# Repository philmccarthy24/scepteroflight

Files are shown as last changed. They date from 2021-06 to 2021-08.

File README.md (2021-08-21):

# Scepter of Light
## 3D printable prop

*Phil McCarthy, August 2021*

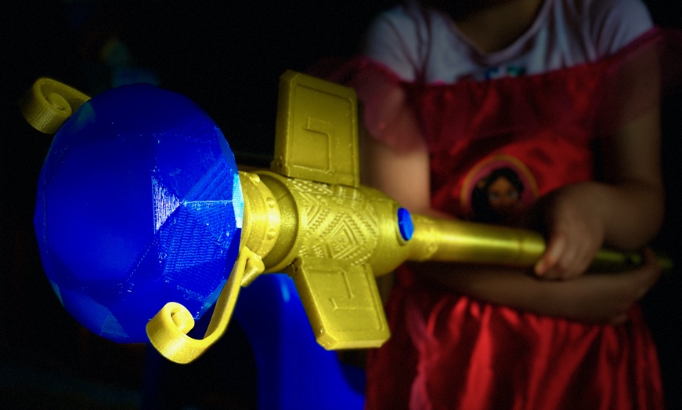
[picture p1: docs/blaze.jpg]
blaze


### What is this?
A 3D printed version of the Scepter of Light from Elena of Avalor, created by Phil McCarthy over summer 2021.

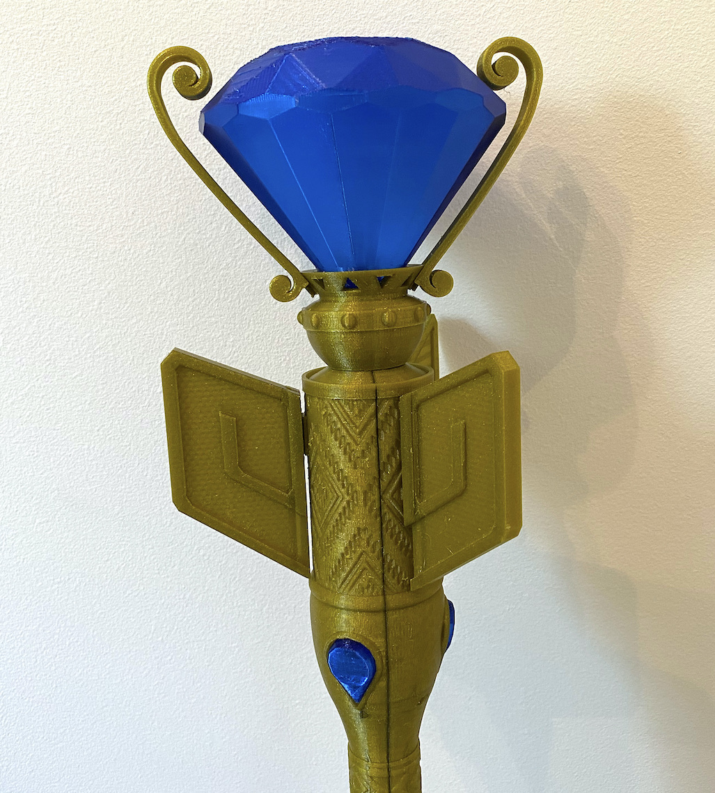
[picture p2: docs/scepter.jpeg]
scepter


### Why?
My daughter loves Elena, and wanted a scepter to go with her costume. I've thought about designing a circuit board and doing some 3D printing for a while - so this was an ideal learning project with the right level of challenge. It took about three months to complete in my spare time.

The scepter lights up and plays music when turned on, and rumbles with "magic" when waved. See a quick [video demo here](https://youtu.be/RlnO9K1_UK8).

I've made [an Instructable](https://www.instructables.com/Scepter-of-Light/) and [a Thing](https://www.thingiverse.com/thing:4937785) to go with this repository, to make it more searchable.

### Features

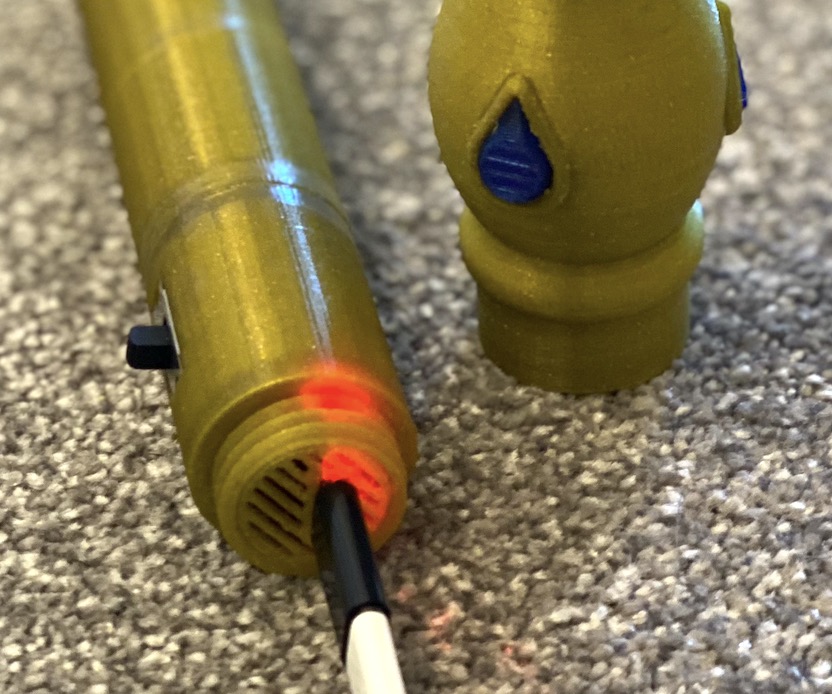
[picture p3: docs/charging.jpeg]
charging
- Easy access charging via MicroUSB port in unscrewable hilt - red light is charging, blue means charged. Grille around port allows heat dissapation during charge. 

- Custom PCB with ULN2003A driver allows independent control of each of the three side ultrabright LEDs, the top ultrabright LED array, and the vibration motor, via the MCU's output pins.

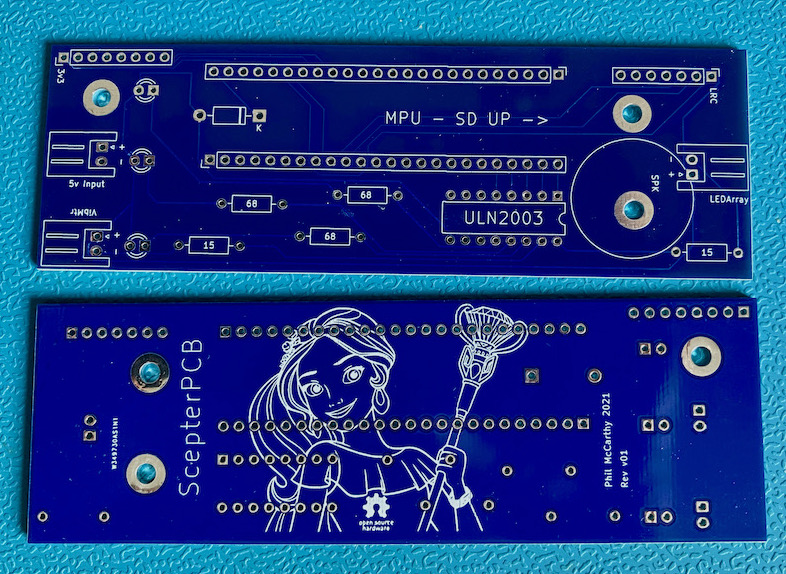
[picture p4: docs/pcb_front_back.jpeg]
pcb
  

- All components on the PCB board are through-hole, allowing easy soldering/assembly, but it's thin enough to fit into the 50mm diameter scepter head.

- High spec Teensy 4.1 MCU with 600 MHz Cortex-M7 processor and 1MB RAM can support gesture recognition via ML (in future).

### What's included in this repository?
Original OpenSCAD designs and related assets for all parts, STL files for unmodified reprints (also Prusa project files which will save you time when slicing if you have a Prusa), KiCAD project files and gerbers for modifying/fabricating the PCB, and documentation.

Included in the documentation is [the full parts list](docs/BOM.md), [assembly instructions](docs/assembly.md), and [the printing settings that worked for me](docs/printing.md) when printing the parts out.

### Any gotchas?

I haven't included wav sound files for potential copyright reasons. You just need to find some appropriate sounds and save them as "theme.wav" and "blaze.wav" on the root of the micro SD card that slots into the microcontroller.

The GY-521 gyro module needs to be mounted onto the PCB upside down, due to a "feature" in the PCB design - this is documented in the assembly instructions.

The sound isn't super-loud. It's acceptably audible, but not room filling. This is because there's little space in the enclosure interior, so I had to opt for a thin 8ohm 0.5W 20mm speaker. As a result the default 9dB gain setting of the MAX98357 distorts the audio through this speaker. I reduced the gain to 6dB by connecting the GAIN pin to Vin, which results in non-distorted (but slightly quieter) audio.

If you have some way of mounting a larger, more powerful speaker (up to 3W), it's possible to get these different gain settings:  

- **15dB** if a 100K resistor is connected between **GAIN** and **GND**
- **12dB** if **GAIN** is connected directly to **GND**
- **9dB** if **GAIN** is not connected to anything
- **6dB** if **GAIN** is connected directly to **Vin** (default PCB wiring)
- **3dB** if a 100K resistor is connected between **GAIN** and **Vin**

You will need to hack the PCB with a craft knife and soldering iron or update the PCB design to achieve these changes.

### What's the future of the project?

I plan to add gesture recognition at some point - the MCU was chosen to be powerful enough to support machine learning and classification of accelerometer data.

I'm not sure when I'm going to get round to coding it in; it might be next year. If you want to implement this yourself, go for it - I'm excited to see what you do!

### Legal stuff
This project is a fan-made artistic prop, not a commercial product, and is free and open source. The PCB design, 3D print designs and MCU firmware are shared under the [GPLv3 license](https://www.gnu.org/licenses/gpl-3.0.en.html).

In particular note the warranty and liability sections - these designs are shared for you to do what you want with them, with the understanding that if they cause harm or damage to you, your property or your loved ones, **you and solely you take full responsibility**.

High capacity Lithium Ion batteries are **dangerous**, should *never* be short circuited, and must be used with care and knowledge. **Please don't assume my circuitry or designs are electrically or mechanically safe.**

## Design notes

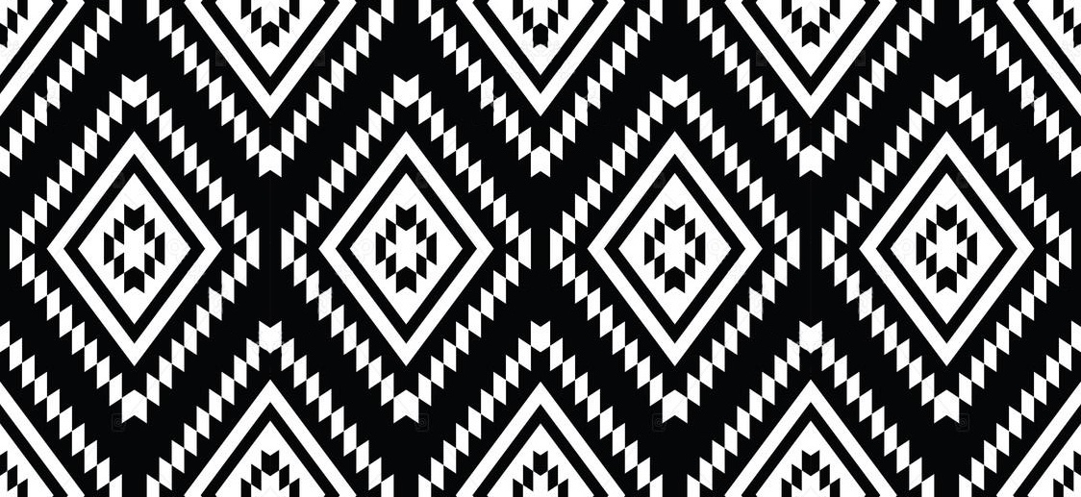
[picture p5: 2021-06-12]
openscad/assets/tiptexture.jpg

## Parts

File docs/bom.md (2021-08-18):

# Scepter of Light
## 3D printable prop

*Phil McCarthy, August 2021*

### BOM / required components list

#### Head assembly

| Item | Quantity | Part Cost (min/bulk) | Line cost | Example link |
|:--|:--|:--|:--|:--|
| M2 3.5x4 brass screw insert | 2 | £11.49 | £0.07 |  [Amazon1](https://www.amazon.co.uk/gp/product/B07QR6GVFJ/ref=ppx_yo_dt_b_asin_title_o03_s00?ie=UTF8&psc=1) |
| M3 5x4 brass screw insert | 3 | As above | £0.07 | As above |
| M2 Stainless Steel pan-head machine screw, 10mm length | 1 |  £8.99 | £0.07 | [Amazon2](https://www.amazon.co.uk/gp/product/B07F152LLX/ref=ppx_yo_dt_b_asin_title_o01_s00?ie=UTF8&psc=1)
| M2 Stainless Steel pan-head machine screw, 12mm length | 1 |  As above | £0.07 | As above |
| M3 nylon PCB screw 4mm length | 3 | £10.76 | £0.11 | [Amazon3](https://www.amazon.co.uk/HALJIA-Circuit-Standoff-Cylinder-Assorted/dp/B06WWBHMQ3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)
| MT3608 voltage regulator | 1 | £6.49 | £1.30 | [Amazon4](https://www.amazon.co.uk/dp/B084V25CCP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)
| Female 2 pin 2.5mm pitch JST SM connector | 1 | £8.59 | £0.02 | [Amazon5](https://www.amazon.co.uk/gp/product/B0716JMHNJ/ref=ppx_yo_dt_b_search_asin_title?ie=UTF8&psc=1) |
| 2 pin JST-XHP plug | 1 | £16.99 | £0.42 | [Amazon6](https://www.amazon.co.uk/gp/product/B07CTH46S7/ref=ppx_yo_dt_b_search_asin_title?ie=UTF8&psc=1) |

#### Components for PCB & LED stalk

| Item | Quantity | Part Cost (min/bulk) | Line cost | Example link |
|:--|:--|:--|:--|:--|
| ULN2003A | 1 | £2.05 | £0.41 | [Rapid1](https://www.rapidonline.com/Catalogue/Search?Query=Uln2003) |
| Teensy 4.1 MCU | 1 | £33.81 | £33.81 | [Amazon7](https://www.amazon.co.uk/Teensy-4-1-Without-Pins/dp/B088D3FWR7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) |
| Micro vibration motor cell 3V 75mA | 1 | £6.49 | £0.81 | [Amazon8](https://www.amazon.co.uk/gp/product/B074M24S21/ref=ppx_yo_dt_b_search_asin_image?ie=UTF8&psc=1) |
| ST 1N5819 Schottky Diode 40V 1A DO41 | 1 | £1.19 | £0.23 | [Rapid2](https://www.rapidonline.com/st-1n5819-schottky-diode-40v-1a-do41-47-2566) |
| Pin headers various | 1 | £5.07 | £5.07 | [Amazon9](https://www.amazon.co.uk/gp/product/B01M69EA9O/ref=ppx_yo_dt_b_asin_title_o09_s00?ie=UTF8&psc=1) |
| 68ohm resistor, through-hole | 3 | £11.99 | £0.03 | [Amazon10](https://www.amazon.co.uk/gp/product/B07P1GWKSJ/ref=ppx_yo_dt_b_asin_title_o09_s00?ie=UTF8&psc=1) |
| 15ohm resistor, through-hole | 2 | As above | £0.02 | As above |
| 5mm ultrabright white LEDs 3V(f) 20mA | 6 | £4.32 | £0.24 | [Amazon11](https://www.amazon.co.uk/gp/product/B01AUI4VQU/ref=ppx_yo_dt_b_asin_title_o03_s00?ie=UTF8&psc=1) |
| JST-XH S2B 2 pin 2.5 pitch header | 2 | £1.66 | £0.16 | [Rapid3](https://www.rapidonline.com/jst-s2b-xh-a-lf-sn-2-pole-side-entry-xh-series-p2-5mm-22-5340) |
| JST-XH B2B 2 pin 2.5 pitch header | 2 | As Amazon6 | £0.84 | As Amazon6 |
| 2 pin JST-XHP plug | 1 | As Amazon6 | £0.42 | As Amazon6 |
| MAX98357A | 1 | £5.92 | £5.92 | [CoolComponents1](https://coolcomponents.co.uk/products/i2s-3w-class-d-amplifier-breakout-max98357a?_pos=2&_sid=e4bcb1d9f&_ss=r) |
| 20mm 0.5W 8ohm flat speaker | 1 | £10.10 | £2.02 | [RS1](https://uk.rs-online.com/web/p/miniature-speakers/1797441)
| GY-521 MPU6050 | 1 | £6.99 | £2.33 | [Amazon12](https://www.amazon.co.uk/gp/product/B07P5YXBXV/ref=ppx_yo_dt_b_search_asin_image?ie=UTF8&psc=1) |
| 16GB micro SD card | 1 | £4.68 | £4.68 | [Amazon15](https://www.amazon.co.uk/gp/product/B073K14CVB/ref=ppx_yo_dt_b_search_asin_image?ie=UTF8&psc=1)

#### Battery module

| Item | Quantity | Part Cost (min/bulk) | Line cost | Example link |
|:--|:--|:--|:--|:--|
| Male 2 pin 2.5mm pitch JST SM connector | 1 | As Amazon5 | £0.02 | As Amazon5 |
| 18650 battery holder (for terminal parts) | 1 | £6.92 | £0.69 | [Amazon13](https://www.amazon.co.uk/gp/product/B075TZF7NN/ref=ppx_yo_dt_b_search_asin_image?ie=UTF8&psc=1) |
| TP4056 charging module | 1 | £2.99 | £0.60 | [Amazon14](https://www.amazon.co.uk/gp/product/B01DRT4PWY/ref=ppx_yo_dt_b_search_asin_title?ie=UTF8&psc=1) |
| Panel mount slide switch | 1 | £3.19 | £3.19 | [RS2](https://uk.rs-online.com/web/p/slide-switches/7347312/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) |
| 18650 2500mAH 3.7v LIon rechargeable battery | 1 | £4.99 | £4.99 | [FogStar1](https://www.fogstar.co.uk/products/samsung-25r-br-2500mah-20a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) |

#### Miscellaneous
22 gauge wires, eg [from here](https://www.amazon.co.uk/gp/product/B00B4ZQ3L0/ref=ppx_yo_dt_b_search_asin_image?ie=UTF8&psc=1).

This comes to £68.61 for all the components required for a single sceptre build, not including minimum quantities required, 3D printing costs or PCB fabrication costs. Worth noting that half the component cost is the (massively overspec'd until machine learning is added) MCU; you will be able to redesign cheaper if you don't need gesture recognition.

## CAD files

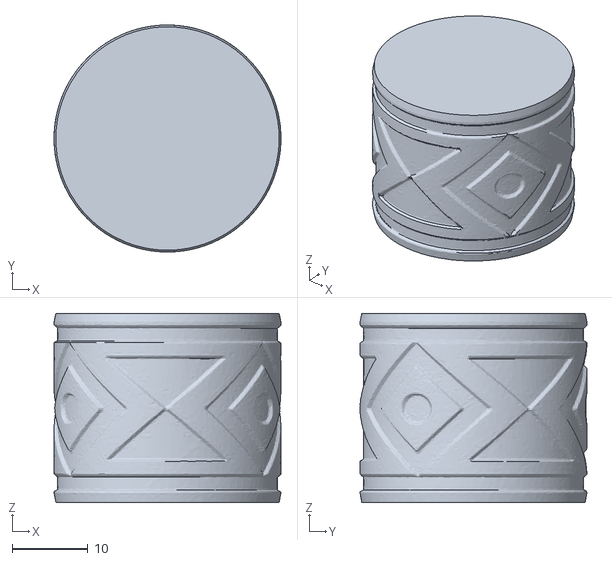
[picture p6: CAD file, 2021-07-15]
openscad/assets/scepterheadjoin.stl
30.0 x 30.0 x 25.0

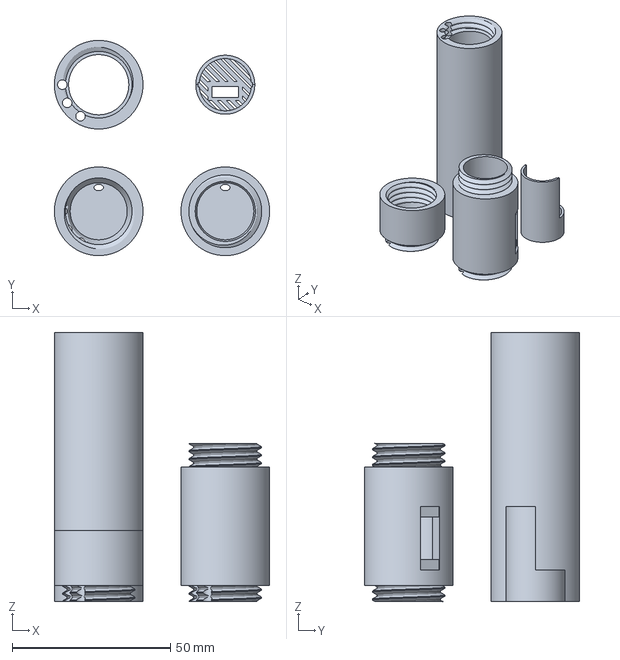
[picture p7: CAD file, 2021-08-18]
stl/batterymodule.3mf
68.0 x 68.0 x 85.0 mm

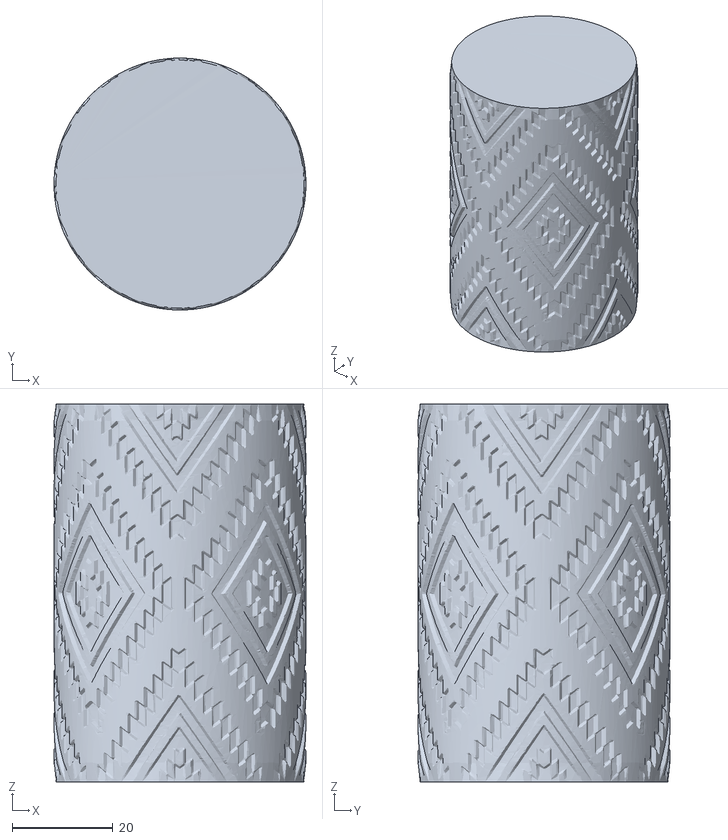
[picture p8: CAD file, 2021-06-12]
openscad/assets/scepterheadwrap.stl
50.0 x 50.0 x 75.0

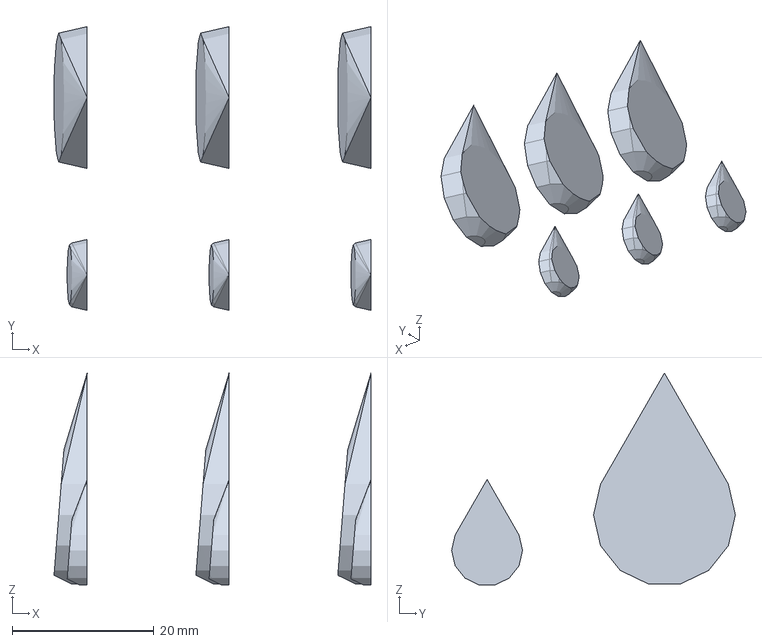
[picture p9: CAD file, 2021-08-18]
stl/teargems.3mf
44.7 x 40.0 x 29.9 mm

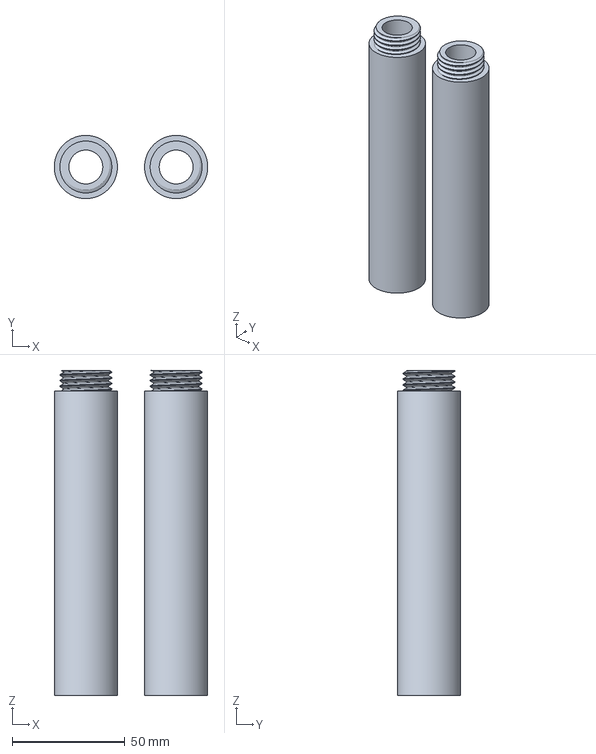
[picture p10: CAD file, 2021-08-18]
stl/shaft.3mf
68.0 x 28.0 x 144.0 mm

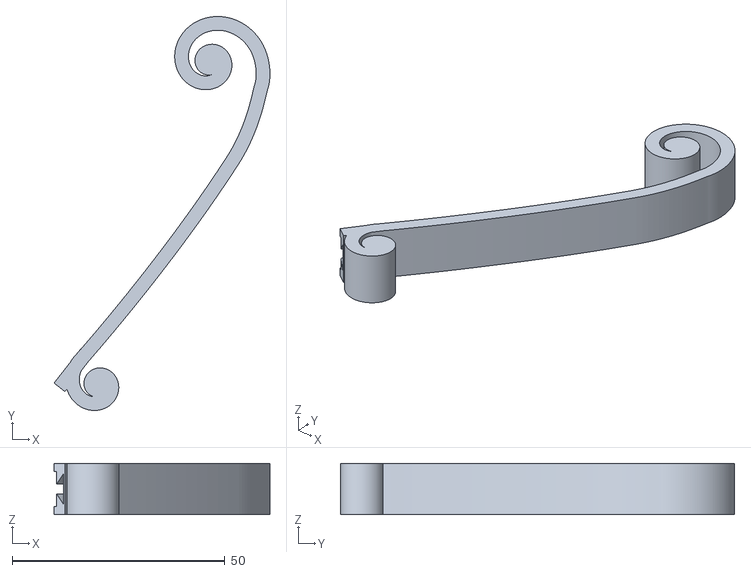
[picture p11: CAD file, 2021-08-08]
stl/gem_curl.stl
50.7 x 92.5 x 12.0

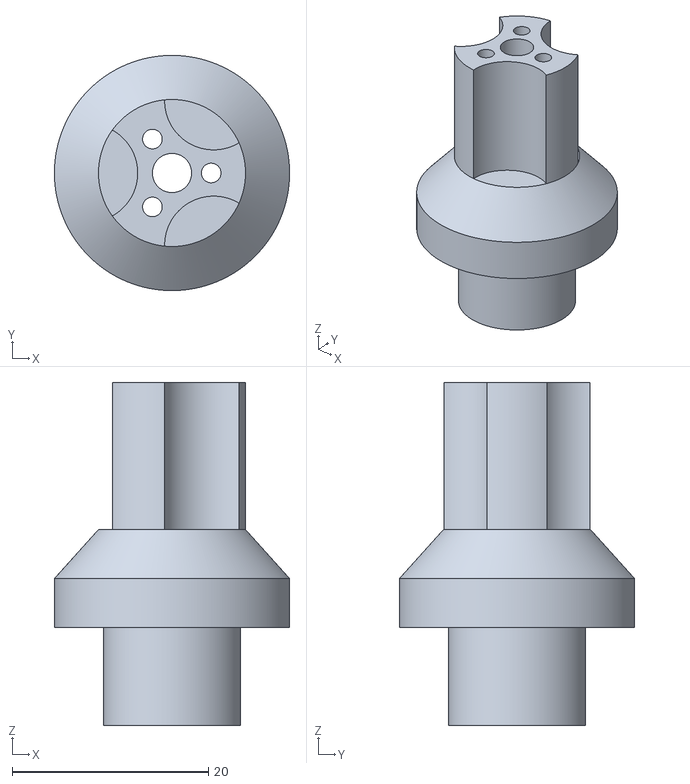
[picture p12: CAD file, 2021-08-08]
stl/stalk.stl
24.0 x 24.0 x 35.0

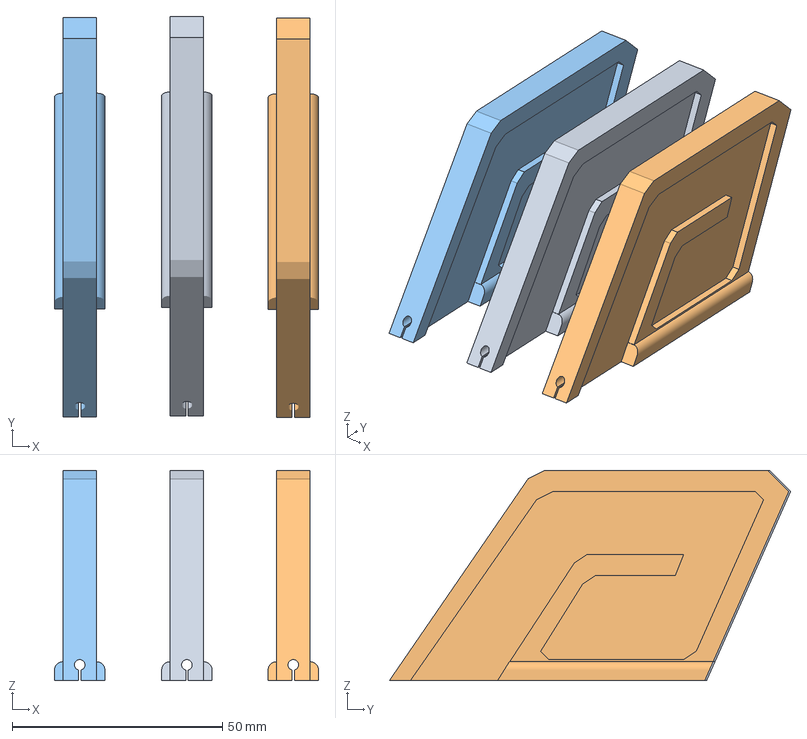
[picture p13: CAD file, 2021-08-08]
stl/headwing.3mf
62.8 x 95.5 x 50.0 mm
headwing.stl x 3

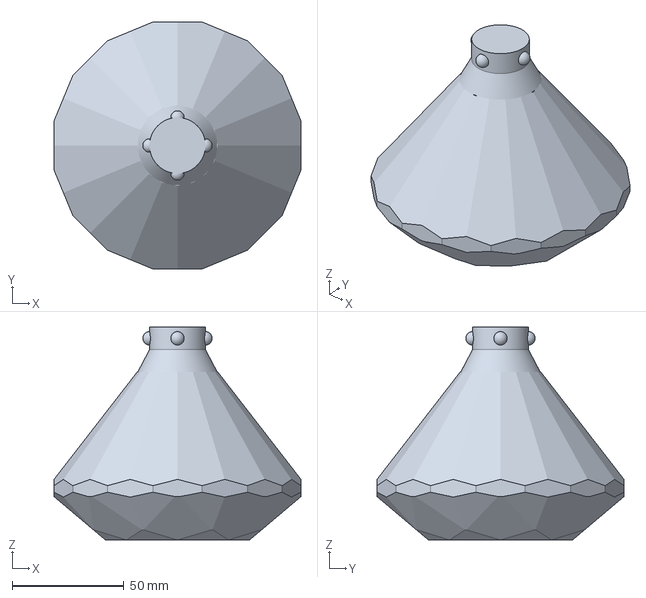
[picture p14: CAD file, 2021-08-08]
stl/gem.3mf
110.5 x 110.5 x 95.2 mm

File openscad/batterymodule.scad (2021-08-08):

use <common.scad>
use <BOSL/constants.scad>
include <BOSL/threading.scad>

$fn = 250;

/****************************************************
* MK4 18650 battery module design
* Phil McCarthy, 2021
* 
* Distributed under the terms of the GPLv3 license:
* https://www.gnu.org/licenses/gpl-3.0.en.html
****************************************************/

shaftDiameter = 28;
batteryDiameter = 19;
batteryLength = 65 - 2; // 1mm less on each side for tension on spring terminals
batteryConnectorSpace = 6;
batteryCompartmentScrewLength = 5;
wireDiameter = 3;
screwThreadPitch = 2.5;


// Main 18650 battery compartment, with 3mm diameter wire runs going down the side
translate([-40,0,0])
batteryCompartment(length=batteryLength + (batteryConnectorSpace * 2) + (batteryCompartmentScrewLength * 2), outerDiameter=shaftDiameter, innerDiameter=batteryDiameter, terminalScrewTapLength=batteryCompartmentScrewLength, terminalScrewTapDiameter=shaftDiameter-5, terminalScrewPitch=screwThreadPitch);

// Positive terminal screw-on adaptor, bolt to bore/tap. This
// has the JST SM connector sticking out, for connection to
// PCB
translate([-40,-40,0])
positiveTerminalAdaptor();

// Negative terminal screw-on adaptor, bolt to bolt with space
// for on/off slide switch and TO4056 support housing.
translate([0,-40,0])
negativeTerminalAdaptor();

// TO4056 support
TP4056holder();


// this is the battery terminal plug, with a shaft screw added to connect
// to upper shaft sections
module positiveTerminalAdaptor() {
    
    difference() {
        union() {
            batteryTerminalPlug(length=12.5, outerDiameter=shaftDiameter, innerDiameter=batteryDiameter, terminalScrewLength=5, terminalScrewDiameter=shaftDiameter-5, terminalScrewPitch=screwThreadPitch, terminalPlateDepth=2);
            translate([0,0,12.5]) cylinder(h=10, d=shaftDiameter);
        }
        // hollow widening to upper shaft screw tap
        translate([0,0,5]) cylinder(h=5+screwThreadPitch, d1=(shaftDiameter-5)-screwThreadPitch*2,d2=shaftDiameter-5);
        // connection screw tap
        translate([0, 0, 12.5]) threaded_rod(d = shaftDiameter - 5, l = 11, pitch = screwThreadPitch, internal = true, slop = 0.25, orient=ORIENT_Z, align=V_UP);
    };
}

// this is the battery terminal plug, with housing inside a plug added for
// on off switch and TP4056 module
module negativeTerminalAdaptor() {
    
    accessPortRadius = ((batteryDiameter + 4) / 2) + 1.5;
    
    difference() {
        union() {
            // plug with terminal glued on outside
            batteryTerminalPlug(length=12.5, outerDiameter=shaftDiameter, innerDiameter=batteryDiameter, terminalScrewLength=5, terminalScrewDiameter=shaftDiameter-5, terminalScrewPitch=screwThreadPitch, terminalPlateDepth=2);
            // body of adaptor
            translate([0,0,12.5]) cylinder(h=30, d=shaftDiameter);
            // hollow plug to connect to hilt, which will contain TO4056 housing
            translate([0, 0, 40]) threaded_rod(d = shaftDiameter - 5, l = 10, pitch = screwThreadPitch, slop=0, orient=ORIENT_Z, align=V_UP);
        }
        // hollow of adaptor
        translate([0,0,5+screwThreadPitch]) cylinder(h=46, d=batteryDiameter);
        
        // hole for on/off switch
        rotate([0,0,120])
        translate([7/2,-shaftDiameter/2,30])
        rotate([90,90,180]) {
            cube([20, 7, 1]);
            translate([(20-13.5)/2, 0,1]) cube([13.5, 7, 6]);
        };
        
        // ramp to facilitate pushing wires through
        translate([0,0,12.5])
        intersection() {
            cylinder(h=10, r1=accessPortRadius, r2=batteryDiameter/2);
            rotate([0,0,170]) pie(angle=80, radius=accessPortRadius, depth=10);
        }
    };
}

module TP4056holder() {
    coverPlateDepth=1;
    to4056Width=16.5;
    holderLength = 30;
    holderDiameter = shaftDiameter - 9.35;
    
    difference() {
        // main volume
        cylinder(h=holderLength, d=holderDiameter);
        // hollow
        translate([0,0,coverPlateDepth]) cylinder(h=holderLength, d=to4056Width);
        // trailing housing
        translate([-holderDiameter/2,0,10]) cube([holderDiameter,holderDiameter/2,holderLength]);
        // grooves for 4056
        translate([-17.3/2, -1.5/2, coverPlateDepth]) cube([17.3, 1.5, holderLength]);
        // microusb opening
        translate([-8.5/2,-4,-1]) cube([8.5,3.5,3]);
        // grille
        intersection() {
            difference() {
                translate([0,0,-1]) cylinder(h=3, d=to4056Width);
                translate([-11/2,-5,-1]) cube([11,6,3]);
            }
            rotate([0,0,45]) {
                for (x = [0:2:holderDiameter]) {
                    translate([x-holderDiameter/2, -holderDiameter/2, -1]) cube([0.75, holderDiameter, 3]);
                }
            }
        }
    }
}

module batteryTerminalPlug(length, outerDiameter, innerDiameter, terminalScrewLength, terminalScrewDiameter, terminalScrewPitch, terminalPlateDepth) {
    difference() {
        union() {
            // screw with terminal seated on outer face.
            threaded_rod(d = terminalScrewDiameter, l = terminalScrewLength, pitch = terminalScrewPitch, slop=0, orient=ORIENT_Z, align=V_UP);
            // body of adaptor
            translate([0,0,terminalScrewLength]) cylinder(h=length-terminalScrewLength, d=outerDiameter);
        }
        // hollow part of screw
        translate([0,0,terminalPlateDepth]) cylinder(h=terminalScrewLength-terminalPlateDepth, d=terminalScrewDiameter-(terminalScrewPitch*2));
        // widening to main hollow area
        translate([0,0,terminalScrewLength]) cylinder(h=terminalScrewPitch, d1=terminalScrewDiameter-(terminalScrewPitch*2), d2=innerDiameter);
        // main hollow area
        translate([0,0,terminalScrewLength+terminalScrewPitch]) cylinder(h=length-(terminalScrewLength+terminalScrewPitch)+1, d=innerDiameter);
        // hole for terminal prong
        translate([0,7.5,-1]) scale([3,2,1]) cylinder(h=4, d=1);
        // wire runs to access port
        wireDiameter=3;
        wireRunRadius=(innerDiameter + wireDiameter + 1) / 2;
        rotate([0,0,180])
        translate([0,0,-1]) wireRuns(numWires=3, wireRunRadius=wireRunRadius, wireDiameter=wireDiameter, runOffsetAngle=30, runLength=terminalScrewLength+5+1);
        // access port
        translate([0,0,terminalScrewLength+terminalScrewPitch]) rotate([0,0,170]) pie(angle=80, radius=wireRunRadius+(wireDiameter/2), depth=length-(terminalScrewLength+terminalScrewPitch));
    };
}

module batteryCompartment(length, outerDiameter, innerDiameter, terminalScrewTapLength, terminalScrewTapDiameter, terminalScrewPitch) {
    difference() {
        // main volume
        cylinder(h=length, d=outerDiameter);
        // hollow interior
        translate([0,0,-1]) cylinder(h=length+2, d=innerDiameter);
        // bottom screw runs up in z counter-clockwise, with part oriented
        // z up.
        // bottom screw tap, with rotation compensation from trial and error
        // rotate([0,0,240]) - old value
        rotate([0,0,150]) translate([0,0,-terminalScrewPitch]) threaded_rod(d=terminalScrewTapDiameter, l = terminalScrewTapLength+terminalScrewPitch, pitch = terminalScrewPitch, internal = true, slop = 0.25, orient=ORIENT_Z, align=V_UP);
        // top screw tap, with rotation compensation from trial and error
        //rotate([0,0,150]) - old value
        rotate([0,0,180]) translate([0,0,length-terminalScrewTapLength]) threaded_rod(d=terminalScrewTapDiameter, l = terminalScrewTapLength+1, pitch = terminalScrewPitch, internal = true, slop = 0.25, orient=ORIENT_Z, align=V_UP);
        // runs
        wireDiameter=3;
        rotate([0,0,180]) translate([0,0,-1]) wireRuns(numWires=3, wireRunRadius=(innerDiameter + wireDiameter + 1) / 2, wireDiameter=wireDiameter, runOffsetAngle=30, runLength=length+2); 
    }
}

// creates geometry for differencing
module wireRuns(numWires, wireRunRadius, wireDiameter, runOffsetAngle, runLength) {
    for (wireNum = [0:numWires-1]) {
        wireRunAngle = wireNum*runOffsetAngle;
        translate([wireRunRadius * cos(wireRunAngle), wireRunRadius * sin(wireRunAngle),0]) cylinder(h = runLength, d = wireDiameter);
    }
}

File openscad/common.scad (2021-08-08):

/*********************************************
* Common modules for Scepter of Light
* Phil McCarthy, 2021
* 
* Distributed under the terms of the GPLv3 license:
* https://www.gnu.org/licenses/gpl-3.0.en.html
****************************************************/

// render a tear shaped gem
module tear_gem(radius, tip_offset, height) {
    hull($fn=14) {
        difference() {
            union() {
                sphere(r=radius);
                cylinder(h=tip_offset, r1=radius/2, r2=0);
            }
            translate([-radius,-radius,-radius]) cube([radius*2, radius, radius+tip_offset]);
            rotate([4.5,0,0]) translate([-radius,height,-radius]) cube([radius*2, radius-height, radius+tip_offset]);
        };
    };
}

// render a seat for a tear gem
module tear_gem_seat(radius, tip_offset, height) {
    render() {
        difference() {
            tear_gem_seat_outline(radius, tip_offset, height);
            translate([0,0,1]) linear_extrude(height) {
                gem_2d(radius+0.25, tip_offset+0.25);
            };
        }
    }
}

module tear_gem_seat_outline(radius, tip_offset, height) {
    render() {
        difference() {
            minkowski(convexity=3) {
                sphere(r=height/2);
                linear_extrude(1) {
                    gem_2d(radius, tip_offset, 50);
                }
            };
            translate([-radius*2, -radius*2, -height]) cube([(radius+tip_offset)*2, radius*4, height]);
        }
    }
}

module gem_2d(radius, tip_offset, numsides=14) {
    hull($fn=numsides) {
        circle(r=radius);
        translate([tip_offset-((radius/10)/2), 0, 0]) circle(r=radius/10, $fn=3);
    }
}

// center a cube in the xy plane
module centred_xy_cube(dims) {
    translate([-(dims.x/2), -(dims.y/2), 0]) cube(dims);
}

// put child objects in a ring - quite proud of this one :)
module make_ring(ringradius, count) {
    drawangle = 360/count;
    for(item = [0 : count]) {
        a = drawangle * item;
        translate([ringradius * cos(a), ringradius * sin(a)]) rotate([0,0,270+a]) children();
    }
}

// yum
module pie(angle, radius, depth) {
    rotate_extrude(angle = angle, convexity = 10) square([radius,depth]);
}

module pill(xlen, ylen, depth) {
    translate([(ylen/2)-(xlen/2),0,0])
    linear_extrude(depth, true)
    hull() {
        circle(d=ylen);
        translate([xlen-ylen,0,0]) circle(d=ylen);
    }
}

module curve_fastener() {
    scale([1,2,1]){
        translate([0,-2,0]) cube([1,4,10]);
        translate([2,0,0]) rotate([0,0,60]) cylinder(h=10,d=4, $fn=3);
    }
}

module wing_fastener() {
    rotate([0,0,90])
    scale([1,2,1]){
        translate([0,-2,0]) cube([3,4,15]);
        translate([4,0,0]) rotate([0,0,60]) cylinder(h=15,d=4, $fn=3);
    }
}

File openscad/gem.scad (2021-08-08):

/****************************************************
* Scepter of Light Top Gem design
*
* Adapted from a design by Kit Wallace, original at:
* https://github.com/KitWallace/openscad/blob/master/gem.scad
*
* Phil McCarthy, 2021
* 
* Distributed under the terms of the GPLv3 license:
* https://www.gnu.org/licenses/gpl-3.0.en.html
****************************************************/

use <common.scad>

function make_facets(start,increment,limit,axial_angle,height) =
    start <= limit
      ? concat([[start/limit*360, axial_angle, height]] ,
               make_facets(start+increment,increment,limit,axial_angle,height))
      : [] ;

module body(Size=100) {
    cube(Size,center=true);
}

module cut_facet_data(index_angle,axial_angle,height,Width=200,Depth=50) {
     rotate([0,0,index_angle])
        rotate([0,axial_angle,0])
           translate([0,0,Depth/2 + height])
              cube([Width,Width,Depth],center=true);
}

module cut_facets(facets, n) {
   for (i =[0:n-1]) 
       cut_facet(facets[i]);
}

module cut_facet(facet) {
   cut_facet_data(facet[0],facet[1],facet[2]);
}

module gem(facets,n) {
   difference() {
      if (n==1) body(); else gem(facets,n-1);
      cut_facet(facets[n-1]);
   }
}

function brilliant_facets() =
 concat( 
   make_facets(1,1,1,0,2.28),      // table
   make_facets(1,1,1,180,7.8),     // culet
   make_facets(1,2,32,35,5),       // B
   make_facets(4,4,32,30,4.46),    // M
   make_facets(2,4,32,16,3.46),    // S
   make_facets(2,2,32,90,8.5),     // girdle
   make_facets(1,2,32,42+180,6)    // C
 ); 

facets = brilliant_facets();
// echo (len(facets), facets);

difference() {
    translate([0,0,21.5]) rotate([180,0,0]) scale([6.5,6.5,9.5]) gem(facets,len(facets));
    translate([0,0,75]) cylinder(h=25,d=100);
    //translate([0,0,-1]) cylinder(h=74, d=160); // debug
}

// 45 degree cone around bayonet
translate([0,0,75]) cylinder(h=10, d1=35.5,d2=25, $fn=250);
translate([0,0,85]) cylinder(h=10, d=25, $fn=250);
translate([0,0,90]) make_ring(25/2, 4) sphere(d=6, $fn=100); 

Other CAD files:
openscad/gem_curl.scad
openscad/assets/scepterheadjoin.blend
openscad/assets/scepterheadwrap.blend
openscad/head.scad
openscad/headwing.scad
openscad/hilt.scad
openscad/shaft.scad
openscad/stalk.scad
openscad/teargems.scad
openscad/thistle.scad
stl/batterymodule.stl
stl/gem.stl
stl/headwing.stl
stl/shaft.stl
stl/teargems.stl

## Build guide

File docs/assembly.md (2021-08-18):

# Scepter of Light
## 3D printable prop

*Phil McCarthy, August 2021*

### Assembly instructions

See [the BOM](../docs/bom.md) for the list of components required to complete this build. You will also need:

- A soldering iron
- Wire cutters
- Pliers
- A drill
- A multimeter
- Superglue (I used Araldite)
- Gluegun

#### 1. Fabricate PCB

Get the PCB fabricated from a board house using the [gerber files](../pcb/sofpcb_rev01_gerber.zip) (I used [PCBWay](https://www.pcbway.com), they were fairly priced and efficient), and wait two weeks for them to arrive. There's typically a 5 board minimum order.

#### 2. Print parts

Print the STL files. [These are the settings](../docs/printing.md) I found worked for me. Use different settings if they work better for you or your printer. I used [gold filament](https://shop.prusa3d.com/en/prusament/958-prusament-petg-yellow-gold-transparent-1kg.html) for the scepter body parts, and [transparent blue](https://www.amazon.co.uk/gp/product/B07T7MBGVL/ref=ppx_yo_dt_b_search_asin_title?ie=UTF8&psc=1) for the gems. In about a week you should have the following printed parts (red shown instead of blue in photo):

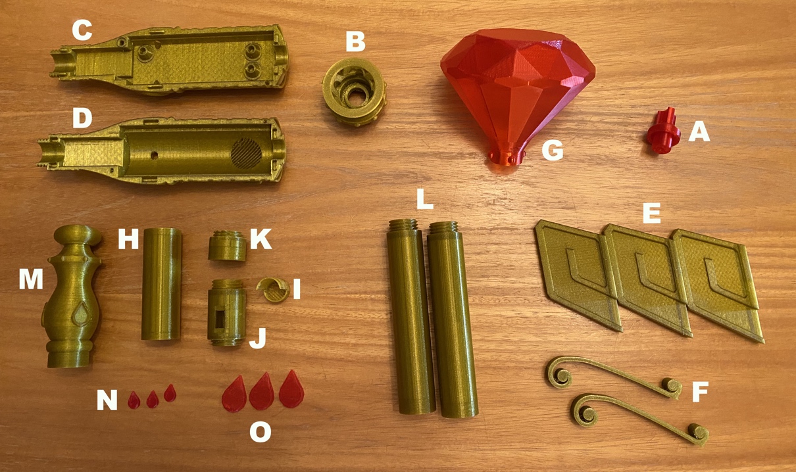
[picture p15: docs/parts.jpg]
parts


- A: LED stalk (blue)
- B: Thistle
- C: Left head
- D: Right head
- E: 3 wings
- F: Top gem curls (gold)
- G: Top gem
- H: 18650 battery case
- I: TP4056 sleeve
- J: Neg terminal screw with switch mount
- K: Pos terminal screw
- L: 2 shaft sections
- M: Hilt
- N: 3 hilt gems
- O: 3 head gems

#### 3. Assemble LED stalk

Take the LED stalk (A), and 3 of the LEDs. Twist the short leads (cathodes) together, and solder on a black wire (long enough to reach the PCB bay below). Solder 3 wires to each of the anodes. 

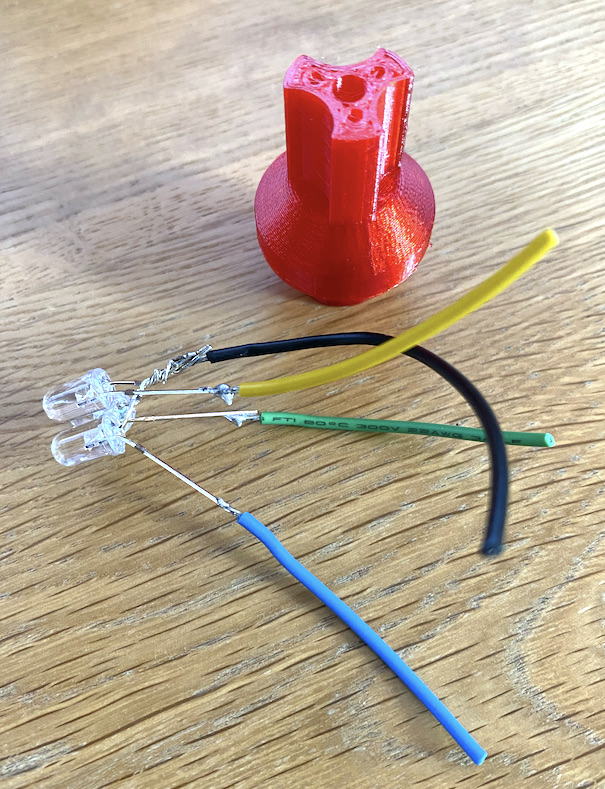
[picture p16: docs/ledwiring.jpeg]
ledwiring


Thread the LED wires through the holes at the top of the LED stalk, black wire in the center, until the LEDs sit flush with the top. Take care that none of the anode leads are left touching the joined cathode lead.

At the base of the stalk, cut, bare and twist the three anode wires together, and solder to them a single positive wire. Put a JST-XH plug on the end of the two stalk wires (note polarity of pcb header).

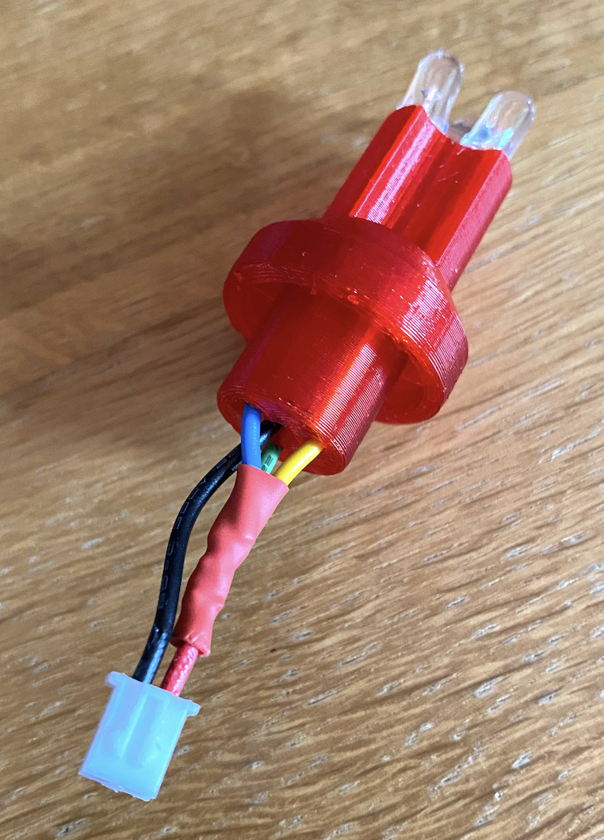
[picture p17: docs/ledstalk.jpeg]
ledstalk


Screw the stalk into the interior of the Thistle (B). 

#### 4. Prepare scepter head

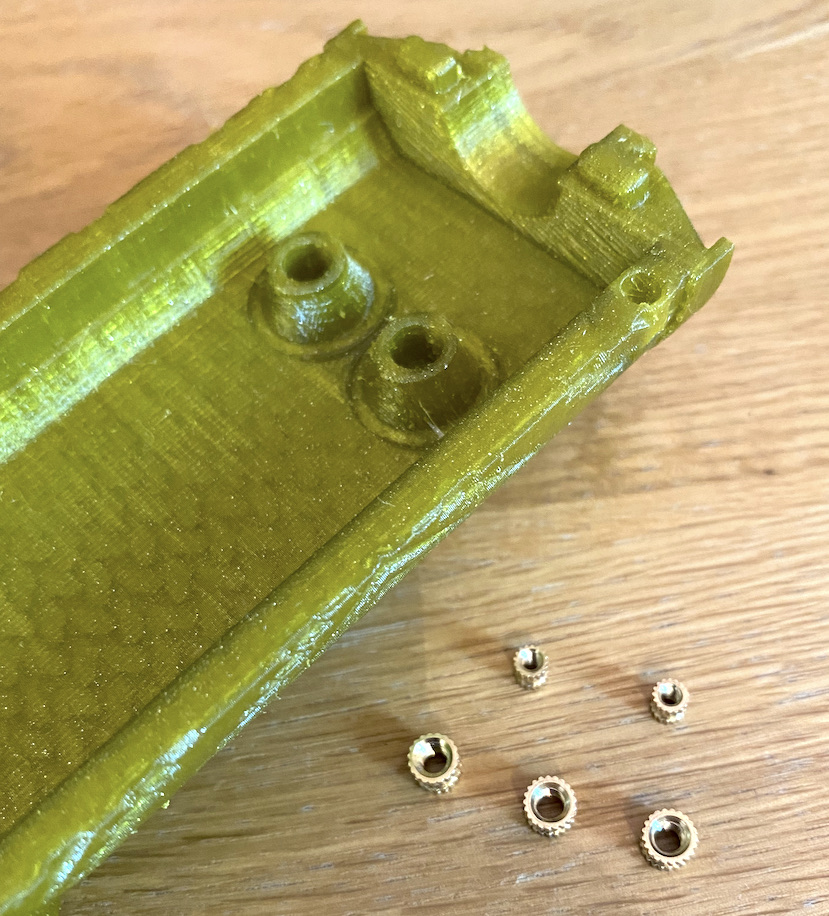
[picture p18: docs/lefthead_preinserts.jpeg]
preinserts


Set your soldering iron to 300 degrees Celcius. Take the M2 and M3 brass inserts and seat them into the corresponding holes in the left head part (C); M2 inserts in top right and bottom left holes, M3 inserts in each PCB standoff hole. Touch the soldering iron tip to each brass insert in turn, pushing it down into the melting plastic. Stop at the last mm, then quickly use a small piece of flat metal to push the inserts fully in, so they sit flush.

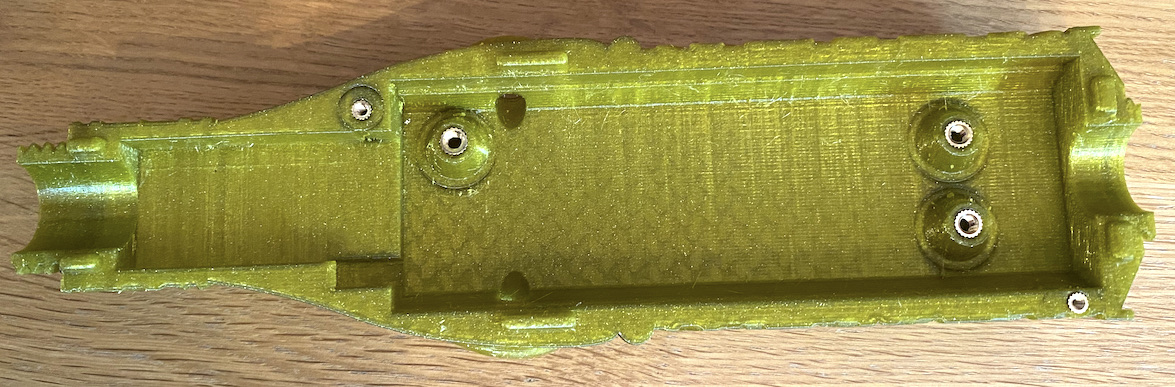
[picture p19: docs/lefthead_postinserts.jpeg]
postinserts


#### 5. Solder components onto PCB

Set your soldering iron back to your preferred temperature - mine is at 350 degrees Celcius. Take your PCB and thread the resistors and shottky diode (cathode on "K" label) through the corresponding holes (see ohm numbers on board for where the resistors go). Turn over and solder to the board. Trim the leads with wire cutters.

Solder on the ULN2003 chip (semi-circle indent up), and all the pin headers. Use a **vertical** instead of right angle 2 pin JST header for the vibration motor connector, due to lack of space in the enclosure. Your PCB should look like the picture below: 

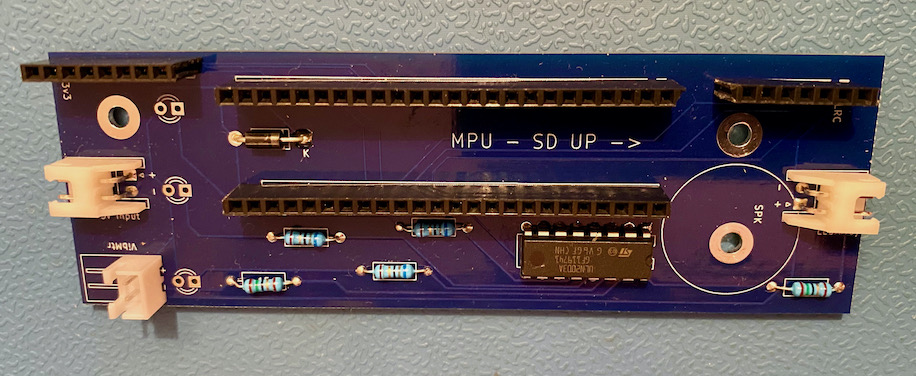
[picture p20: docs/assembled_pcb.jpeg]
pcb_soldered


Solder a 2 pin vertical JST header on the center LED footprint (just above the "5V Power In" JST header), facing up. Create a detachable LED cable for this header by soldering a black and red wire to the cathode and anode leads of an LED respectively. Put a JST-XH plug onto the cable (noting the polarity of the LED header).

#### 6. Setup MCU

Solder male pin headers onto the Teensy MCU. Copy your "theme.wav" and "blaze.wav" sound files onto the root of a micro SD card, and put it into the Teensy's SD slot. Install the [Teensyduino](https://www.pjrc.com/teensy/teensyduino.html) IDE onto your computer, open up the firmware/sol_firmware/sol_firmware.ino sketch and build it (press the "Verify" button). Ignore any compiler warnings. Plug a micro USB cable from the computer into the Teensy. Press the white button on the Teensy to flash the compiled sketch to the MCU. Remove the cable.

#### 7. Mount PCB in scepter head enclosure

Thread 2 LEDs through the underside of the PCB at the corresponding LED footprints at the bottom of the board - long anode lead towards the PCB bottom (where the power connector is).

Place the PCB onto the standoffs in the enclosure bay, so that the 2 LEDs just poke out of the bottom gem seat holes. Solder them in position and trim the leads with wire cutters.

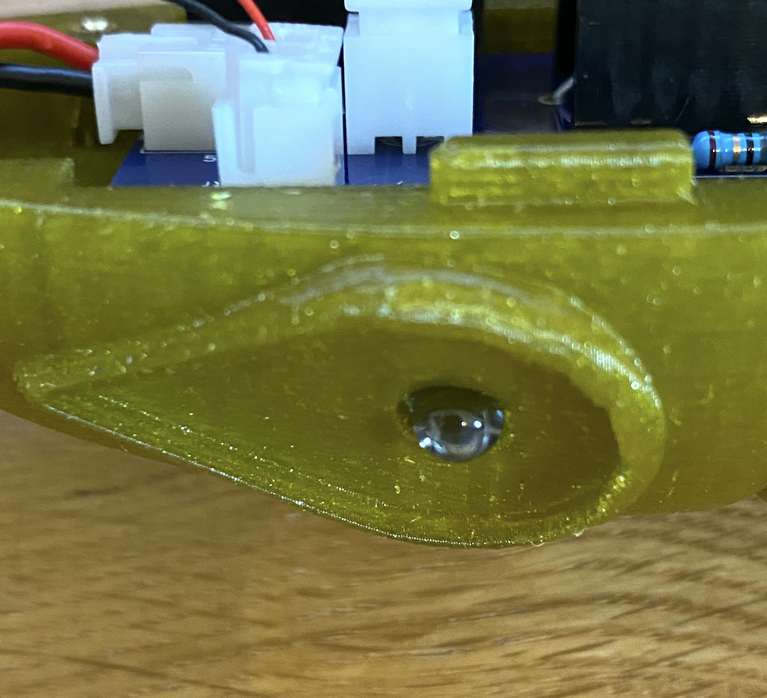
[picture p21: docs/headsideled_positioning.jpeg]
headsideled_positioning


Screw M3 nylon screws into the standoffs to secure the PCB in place.

Solder male pin headers onto the MAX98357A amplifier module (also solder included terminal block) and GY-521 gyro module - solder the header onto the GY-521 **front** rather than back (the PCB design has a "feature" where the GY-521 needs to be mounted upside-down. This doesn't affect anything other than my pride). Solder wires onto a mini-speaker and screw them into the correct holes in the MAX98357A's terminal block.

Solder a female JST-SM connector to the "in" pads of the voltage regulator module and JST-XH connector to the "out" pads. Use a 3.7v power source to supply power to the module. Set your multimeter to measure voltage and touch its probes to the output terminals. Turn the flat screw on the trimmer pot until an output of around 5v is achieved. Place the module in the voltage regulator bay and connect it to the PCB.

Crimp a JST-XH plug onto the leads of a vibration motor (noting polarity) and connect it to the corresponding pin header on the board. Push the Teensy, MAX98357A and GY-521 into the corresponding female pin headers on the PCB. Your enclosure should now look like this: 

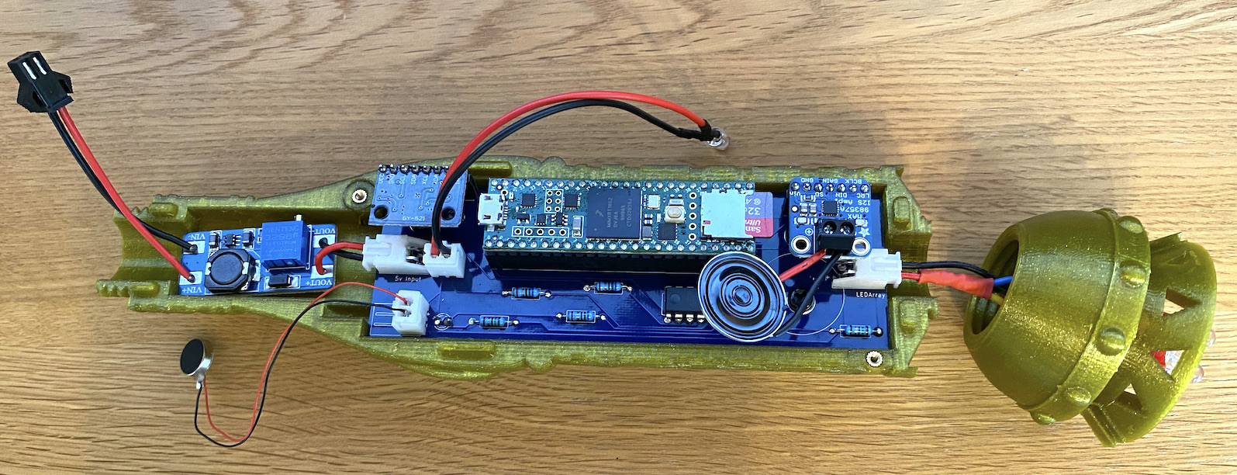
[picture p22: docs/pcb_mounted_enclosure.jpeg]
mounted PCB


Seat the vibration motor vertically into the circular cut-out next to the PCB, and glue it into place with a glue gun. Glue the voltage regulator module in position, and put a dab of gluegun glue around the trimmer pot screw, so that it doesn't twist over time with vibration or shock.

Take the right head part (D), enclosure side up, and put it next to the left head part. Place the LED on the lead into the gem seat hole on the right head part, so that it is just poking through to the outside. Gluegun it into position.

#### 8. Assemble battery module

Take an 18650 holder, butcher it with wire cutters and carefully remove the two metal battery contacts. It will be cheaper and better for the environment to order the battery contact parts directly, but 

1. I don't know what part number they are / which supplier to source them from, and
2. I had the holders spare when I was planning to use them directly in the design.

Use pliers to bend the pins at the base of the battery contacts back (away from the prong) 90 degrees.

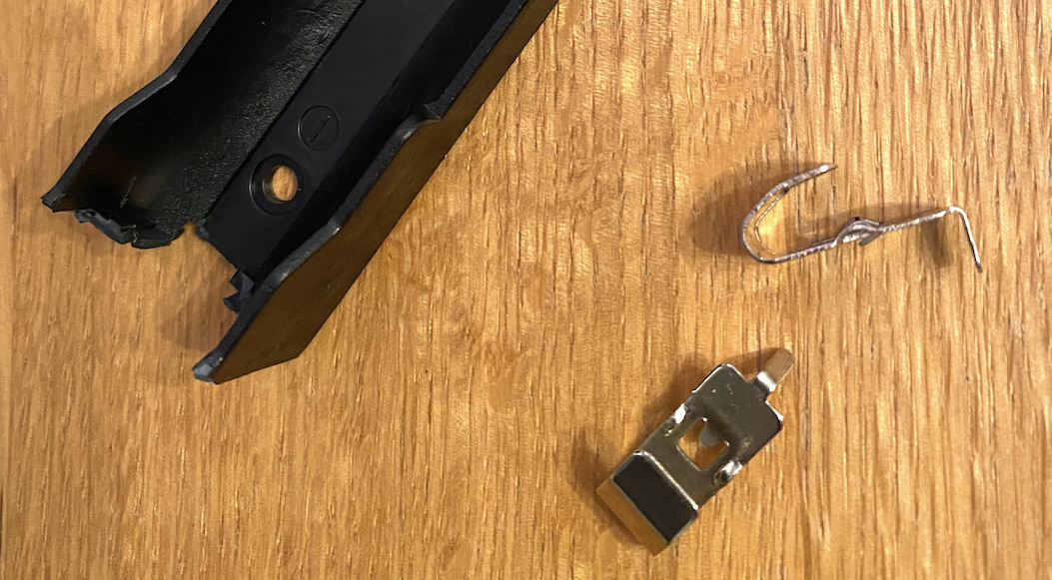
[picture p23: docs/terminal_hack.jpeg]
terminal_hack


Take one of the contacts and solder a red wire to the pin - it should be long enough to reach the length of the battery case part (H) and negative plug part (J) together, plus a little more. Thread the wire through the pin hole on the outside of the positive plug part (K), until the battery contact sits flush on the outer surface of the plug. Take a soldering iron and touch it briefly to the contact, so the thermoplastic around it melts slightly, securing it in place. The image below shows the positive terminal with red wire looped back through a wire run hole for illustrative purposes - don't loop it back yet.

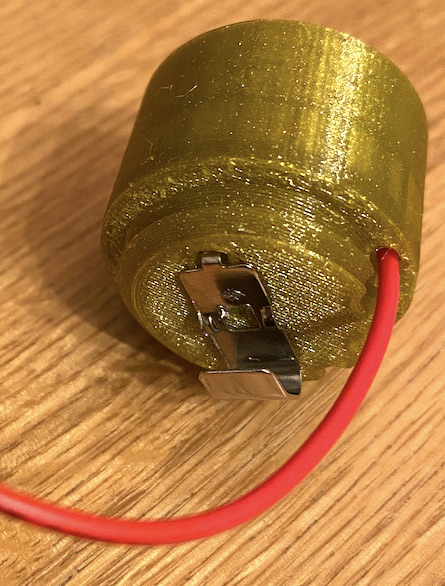
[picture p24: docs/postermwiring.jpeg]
postermwiring


Optionally put superglue in the positive plug screw (gluing the battery module parts and shaft parts together increases material strength when the scepter is being waved around!), and screw it tight into the battery case part (H), until the three cable runs align. Carefully put an 18650 battery into the battery case, so the positive end touches the positive battery contact.

Take the other metal battery contact and do the same with the negative plug screw part (J), so that a fairly short black wire is soldered to the contact, threaded through the pin hole, and the contact is secured to the outer surface of the plug using melted plastic. 

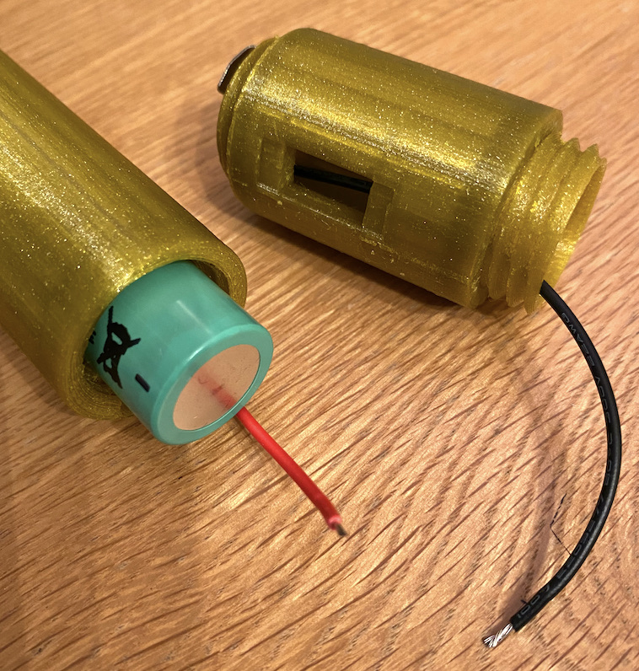
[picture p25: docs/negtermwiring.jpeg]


Again, optionally put superglue around the plug, then screw it tight into the open end of the battery case part (H), until the three cable run holes align.

Loop the red wire back on itself and thread it through one of the cable run holes, so it comes out inside of the negative plug part. Take the red and black battery wires, trim and bare them, and solder them to the TP4056 module's "battery +" and "battery -" pads.

Take the slide switch, and solder a short red wire to the middle pin. Thread it through the switch cutout hole of the negative plug part, and solder to the "out +" pad of the TP4056 module. Cut red and black wires long enough to reach across the battery module and two shaft sections, with a bit of room to spare. Thread the long red wire into a cable run in the positive plug part (K), through the side of the battery case, and out of the negative plug part (J). Thread it out of the switch cutout, and solder it to the switch's top pin. Thread the long black wire into the remaining cable run in the positive plug part (K), through the side of the battery case, and out of the negative plug part (J). Solder it to the "out -" pad of the TP4056 module.

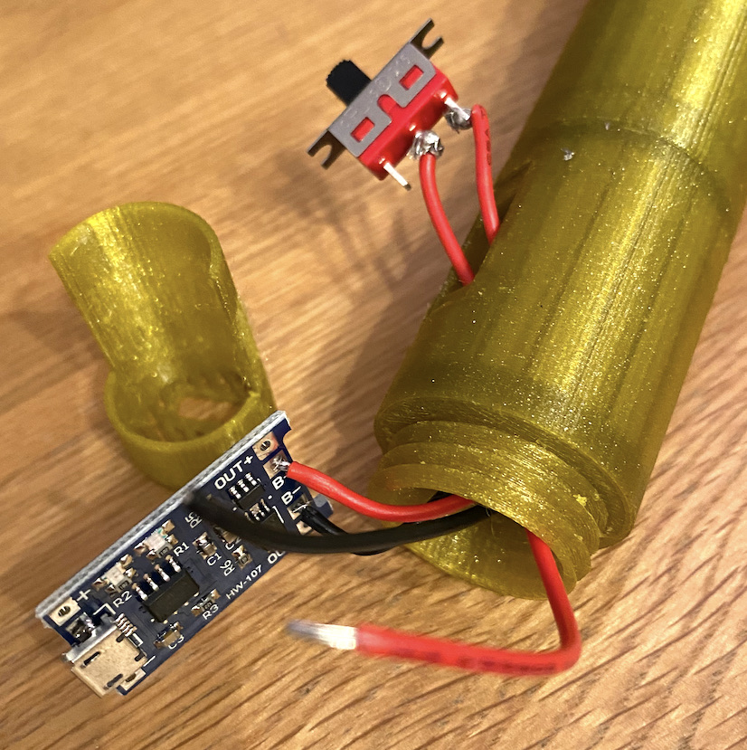
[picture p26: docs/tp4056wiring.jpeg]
tp4056wiring


Take the ends of the long red and black wires, and use your multimeter to test that 3-4.2V is present when the slide switch is at the "on" position, and 0v when at the "off" position. Enure the switch is off, then crimp a JST-SM male plug onto the end of the cable.

Put superglue along the inner edge of the TP4056 sleeve, and slide the TP4056 module into it - the sides of the module should be glued to the sleeve, and the micro USB socket should be accessible through the hole in the grille. Put superglue at the top of the switch cutout, and around the sides of the slide switch. Push the switch down into the cutout. Put superglue around the outer semi-cylindrical surface of the TP4056 sleeve, and push it into the negative plug part (J), until the sleeve face is flush to the screw plug hole. Leave overnight for the glue to dry.

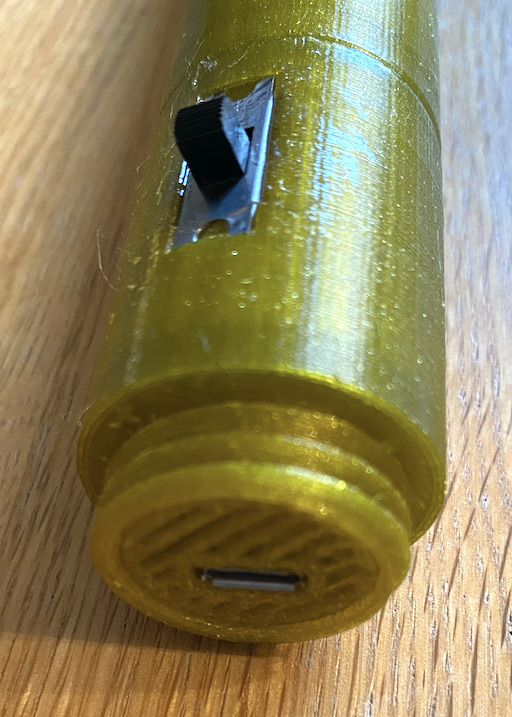
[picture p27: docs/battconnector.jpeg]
battconnector


#### 9. Complete the assembly

Take the shaft sections (L) and screw them together. Thread the long JST-SM power cable through them, and screw the positive battery module to the shaft sections. Optionally superglue all these shaft screw joints.

Superglue the hilt gems (N) into the seat positions in the hilt part (M). Screw the hilt onto the micro USB recharging port plug (**don't glue the hilt on - the recharge port is meant to be accessible!**).

Take the left head part (C) with thitle and LED stalk parts (B and A) connected to the installed PCB, and the right head part (D) connected to the PCB by the top side gem LED cable. Fit the right head part onto the left head part, so the lugs fit together, taking care not to trap any cables. Take the longer M2 bolt and screw it into the hole below one of the side tear gems. Screw the other M2 bolt into the screw hole at the top of the scepter head.

Carefully screw the thistle one turn onto the scepter head, taking care not to dislodge the cable.

Take the hollow head tear gem parts (O), and drill small (2mm) holes in the wider part of their flat back surfaces, taking care not to mark the inside surfaces of the gem fronts. Take a craft knife and cut from each hole to the outer edge. Cut openings large enough for the LEDs to poke into.

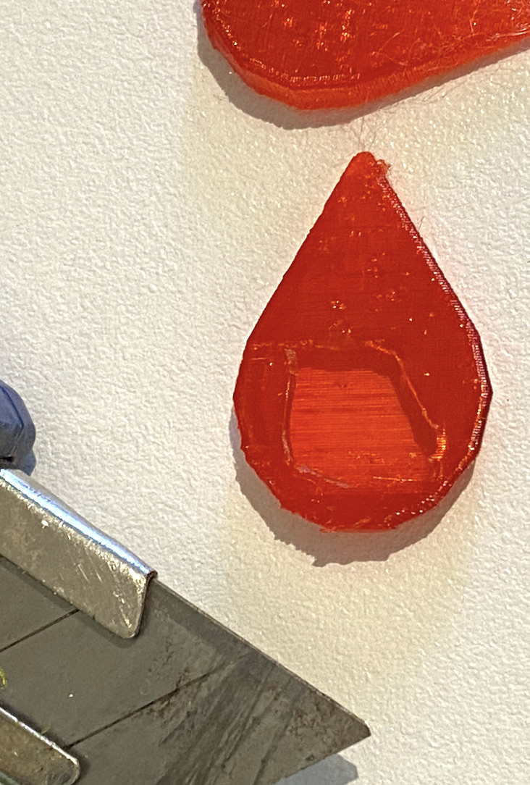
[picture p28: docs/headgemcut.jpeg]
headgemcut


Put a dab of superglue on each side gem seat on the scepter head, and push the side gems into their seats. Take each wing part (E) and place the rectangular opening onto a wing clip ('V' connector) on the scepter head. Carefully slide/work the wing part down until the wing is secured over the textured part of the head (the wing join is designed to flex a small amount and should not snap if you're careful).

Take the top gem part (G) and place it into the thistle part (B) so the bayonet connector bumps slide down into the grooves.

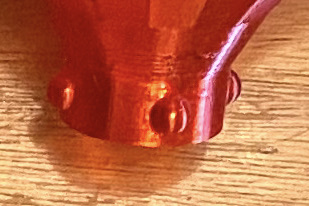
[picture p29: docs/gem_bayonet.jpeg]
gem_bayonet


Twist the gem slightly so the bayonet connector bumps hold the gem in position. Slide the gem curl parts (F) onto the 'V' clips either side of the thistle top.

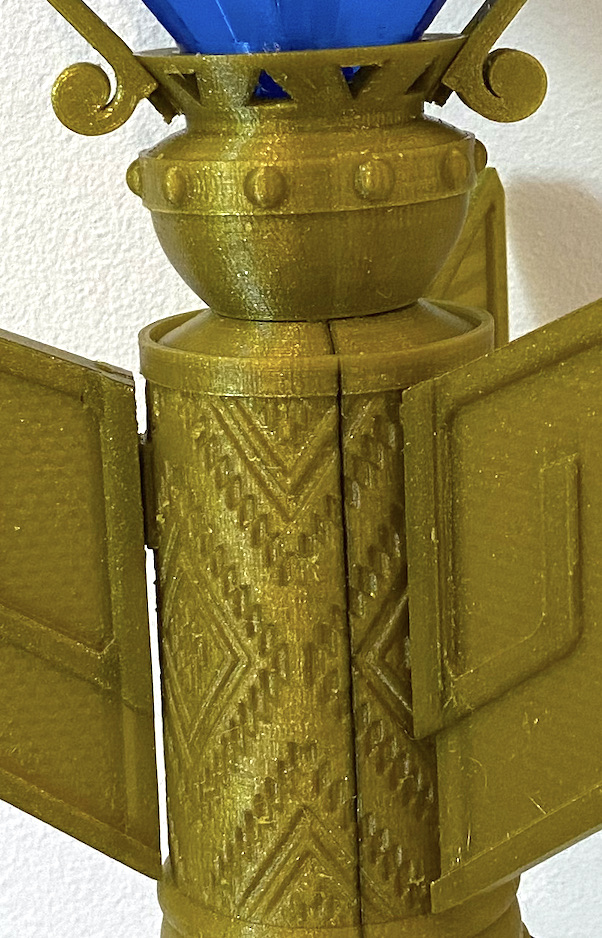
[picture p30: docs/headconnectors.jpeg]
headconnectors
 

Connect the shaft and head power lead JST-SM connectors together. Poke the cable and connector down into the shaft, and screw the shaft to the bottom of the head reasonably tight. I'd recommend against supergluing this screw joint as you may need to service the electronics in the head enclosure.

This completes assembly of your Scepter of Light.

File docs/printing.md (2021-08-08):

# Scepter of Light
## 3D printable prop

*Phil McCarthy, August 2021*

### Printing suggestions
I used [gold filament](https://shop.prusa3d.com/en/prusament/958-prusament-petg-yellow-gold-transparent-1kg.html) for the scepter body parts, and [transparent blue](https://www.amazon.co.uk/gp/product/B07T7MBGVL/ref=ppx_yo_dt_b_search_asin_title?ie=UTF8&psc=1) for the gems. Please see below for the various print settings I found to work:

| Part Ref | Part name | Printing setting that worked | Filament colour used |
| --- | --- | --- | --- |
| A | LED stalk | 0.2mm layer height, 100% infill, supports on build surface, support blockers in LED wire channels | Transparent blue |
| B | Thistle | 0.1mm layer height, supports everywhere, 20% infill | Yellow gold |
| C | Left head | Printed vertically oriented, supports everywhere. 0.15mm layer height, 20% infill, with 100% infill modifiers on top/bottom screw parts and wing clips. | Yellow gold |
| D | Right head | Printed vertically oriented, supports everywhere. 0.15mm layer height, 20% infill, with 100% infill modifiers on top/bottom screw parts and wing clips. | Yellow gold |
| E | Wings | 0.2mm layer height, supports everywhere. 20% infill with 3D honeycomb pattern, first 7mm height modifier with 100% infill. Horizontal support blocker in cylinder of clip flex channel, so you don't get impossible-to-remove support material. | Yellow gold |
| F | Gem curls | 0.2mm layer height, supports everywhere. | Yellow gold |
| G | Top Gem | 0.2mm layer height, 0% infill, 0 top layer, 1 bottom layer, 1 perimeter layer, supports everywhere. | Transparent blue |
| H | Battery case | 0.15mm layer height, 20% infill, support blocker in wire channels | Yellow gold |
| I | TP4056 sleeve | 0.15mm layer height, 100% infill | Yellow gold |
| J | Neg terminal block | 0.15mm layer height, 20% infill, 100% infill modifier for screw plug section | Yellow gold |
| K | Pos terminal block | 0.15mm layer height, 20% infill, 100% infill modifier for screw plug section | Yellow gold |
| L | Shaft | 0.2mm layer height | Yellow gold |
| M | Hilt | 0.1mm layer height, supports everywhere. | Yellow gold |
| N | Hilt gems | 0.15mm layer height 100% infill | Transparent blue |
| O | Head gems | 0.2mm layer height, 0% infill, 1 layer for top, bottom and perimiter. Vertically orient so gem tip is up, supports everywhere. | Transparent blue |

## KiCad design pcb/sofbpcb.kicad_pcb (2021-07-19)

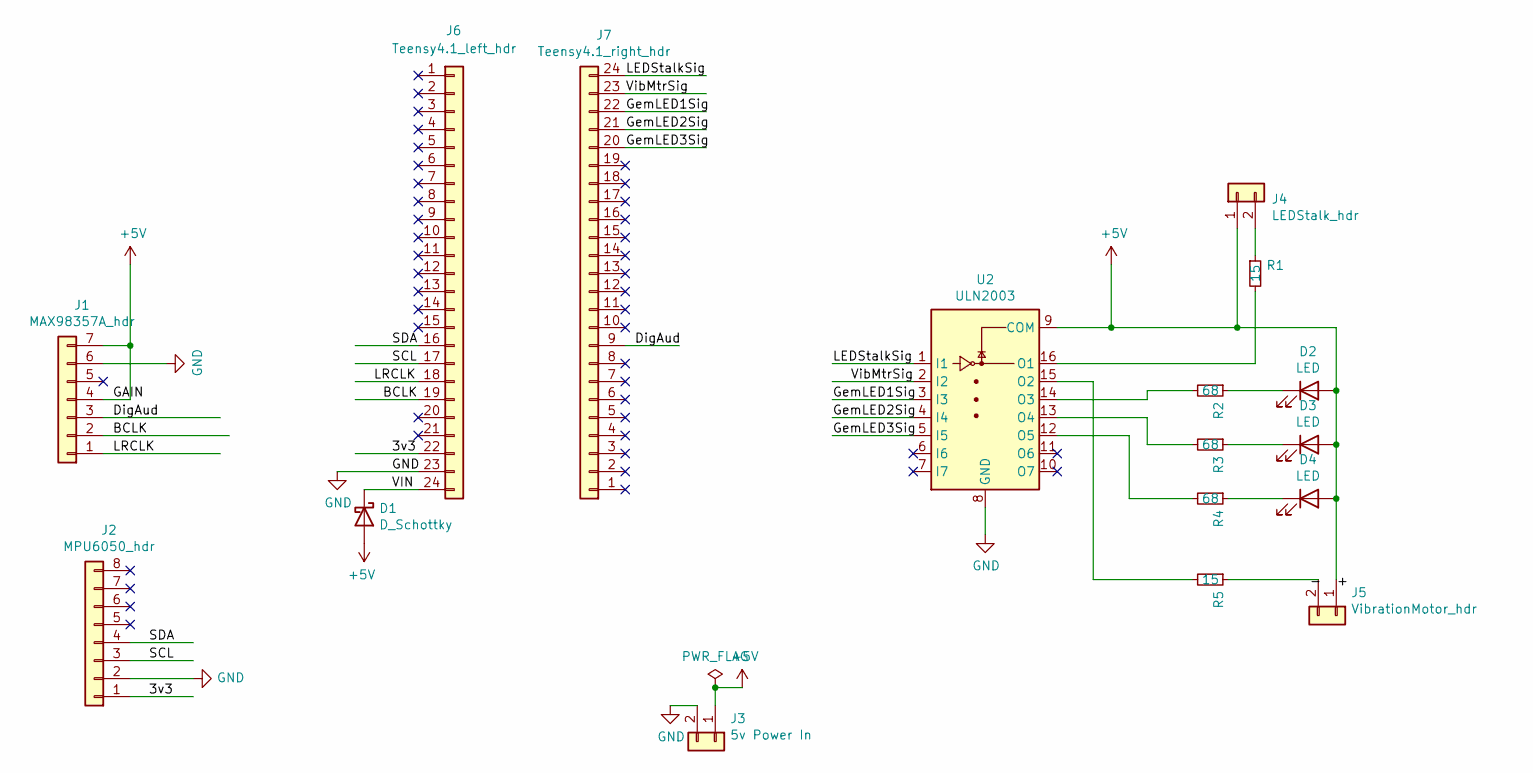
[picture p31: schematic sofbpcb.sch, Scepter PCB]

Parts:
D1: D_Schottky; D_DO-41_SOD81_P10.16mm_Horizontal
D2, D3, D4: LED; LED_D3.0mm
J1: MAX98357A_hdr; PinHeader_1x07_P2.54mm_Vertical
J2: MPU6050_hdr; PinHeader_1x08_P2.54mm_Vertical
J3: 5v Power In; JST_XH_S2B-XH-A_1x02_P2.50mm_Horizontal
J4: LEDStalk_hdr; JST_XH_S2B-XH-A_1x02_P2.50mm_Horizontal
J5: VibrationMotor_hdr; JST_XH_S2B-XH-A_1x02_P2.50mm_Horizontal
J6: Teensy4.1_left_hdr; PinHeader_1x24_P2.54mm_Vertical
J7: Teensy4.1_right_hdr; PinHeader_1x24_P2.54mm_Vertical
R1, R5: 15; R_Axial_DIN0207_L6.3mm_D2.5mm_P10.16mm_Horizontal
R2, R3, R4: 68; R_Axial_DIN0207_L6.3mm_D2.5mm_P10.16mm_Horizontal
U2: ULN2003; DIP-16_W7.62mm

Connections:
+5V: D1.2 (A), D2.2 (A), D3.2 (A), D4.2 (A), J1.4, J1.7, J3.1, J4.1, J5.1, U2.9 (COM)
/3v3: J2.1, J6.22
/BCLK: J1.2, J6.19
/DigAud: J1.3, J7.9
/GemLED1Sig: J7.22, U2.3 (I3)
/GemLED2Sig: J7.21, U2.4 (I4)
/GemLED3Sig: J7.20, U2.5 (I5)
/LEDStalkSig: J7.24, U2.1 (I1)
/LRCLK: J1.1, J6.18
/SCL: J2.3, J6.17
/SDA: J2.4, J6.16
/VIN: D1.1 (K), J6.24
/VibMtrSig: J7.23, U2.2 (I2)
GND: J1.6, J2.2, J3.2, J6.23, U2.8 (GND)
unnamed: D2.1 (K), R2.1
unnamed: D3.1 (K), R3.1
unnamed: D4.1 (K), R4.1
unnamed: J4.2, R1.1
unnamed: J5.2, R5.1
unnamed: R1.2, U2.16 (O1)
unnamed: R2.2, U2.14 (O3)
unnamed: R3.2, U2.13 (O4)
unnamed: R4.2, U2.12 (O5)
unnamed: R5.2, U2.15 (O2)

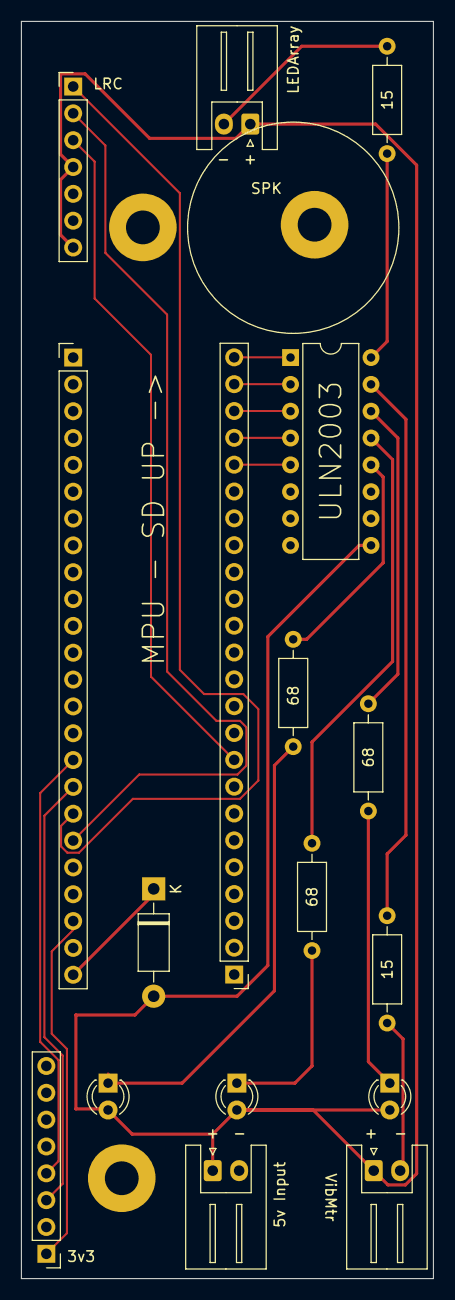
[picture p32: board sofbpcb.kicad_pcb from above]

Board: 2 copper layers, 39.0 x 119.0 mm, 17 parts (0 on the bottom side), 24 nets.

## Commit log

2021-06-17 Prototype hilt and shaft, head mid-design
    [common.scad, head.scad, headwing.scad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]
2021-06-22 Made shaft and hilt thinner, new battery module design
    [batterymodule.scad, common.scad, head.scad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]
2021-06-22 MK3 battery module design
    [batterymodule.scad]
2021-06-29 Finished big diamond design and thistle mount body
    [batterymodule.scad, gem.scad, head.scad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]
2021-07-06 Gem, curls and thistle complete
    [common.scad, gem.scad, gem_curl.scad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]
2021-07-12 head prototyping
    [common.scad, head.scad, headwing.scad]
2021-07-15 Tweaks to head enclosure, circuit schematic complete
    [head.scad, scepterheadjoin.blend, scepterheadjoin.stl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]
2021-07-15 Added teensy kicad lib
2021-07-15 Tweak to schematic pwr in
    [sofbpcb.sch]
2021-07-15 Combined led stalk resistors into one
    [sofbpcb.sch]
2021-07-18 pcb mid design. nearly there
    [head.scad, sofbpcb.kicad_pcb, sofbpcb.sch]
2021-07-19 PCB design complete, just needs silk screen tidied up
    [head.scad, sofbpcb.kicad_pcb, sofbpcb.sch]
2021-07-19 Added silk screen, plotted gerbers for pcb fab
    [sofbpcb.kicad_pcb]
2021-07-20 Tidying KiCad project folder
2021-07-20 GitIgnore KiCad temp files
    [sofbpcb-B_Cu.gbl, sofbpcb-B_Mask.gbs, sofbpcb-B_Paste.gbp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]
2021-07-30 Fixes to head prior to first gold print
    [common.scad, head.scad, headwing.scad]
2021-08-08 Tidied up files and folders, added proper readme, started on assembly instructions
    [batterymodule.3mf, batterymodule.scad, batterymodule.stl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]
2021-08-18 Completed assembly instructions, fixes to STLs
    [batterymodule.3mf, shaft.3mf, teargems.3mf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]
2021-11-24 Made head thistle screw slightly longer
    [head.scad]
